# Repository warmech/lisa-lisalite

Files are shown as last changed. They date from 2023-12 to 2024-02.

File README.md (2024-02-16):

# Lisa Lite

The Lisa Lite is an adapter card for the Lisa 2 and 2/5 that allows a Twiggy drive to be replaced by a 400K Sony 3.5" floppy drive. Most of the signals are passed directly from the Twiggy interface to the Sony interface, though the motor clock signal on the Twiggy side is used as the basis (along with a 5MHz oscillator) for generating the PWM signal used to drive the Sony drive.

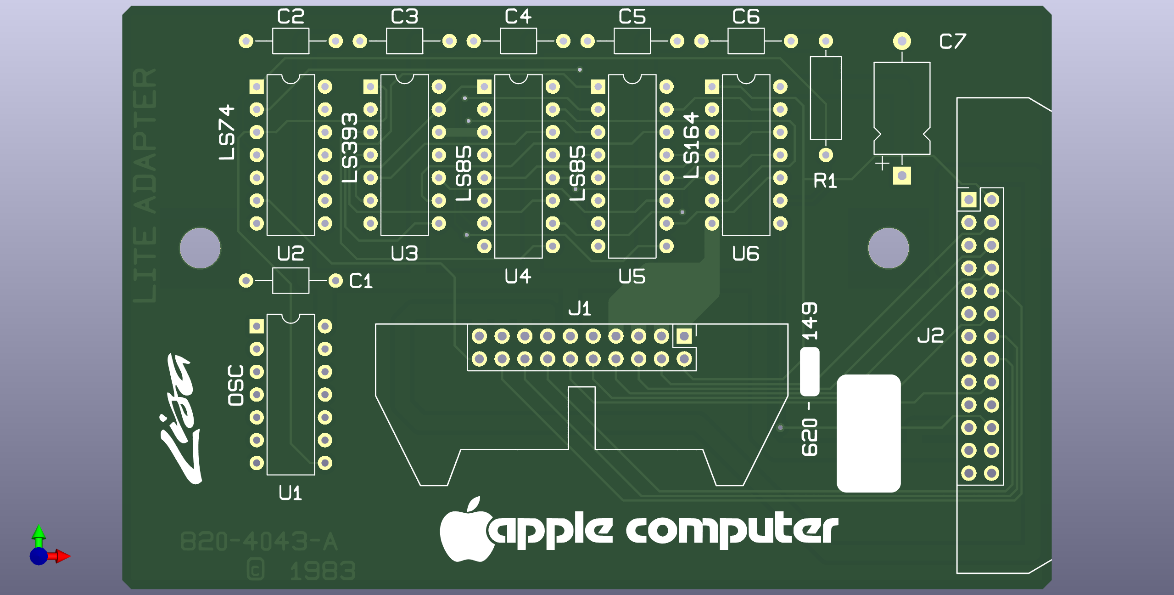
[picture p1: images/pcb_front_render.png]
Lisa Lite Front


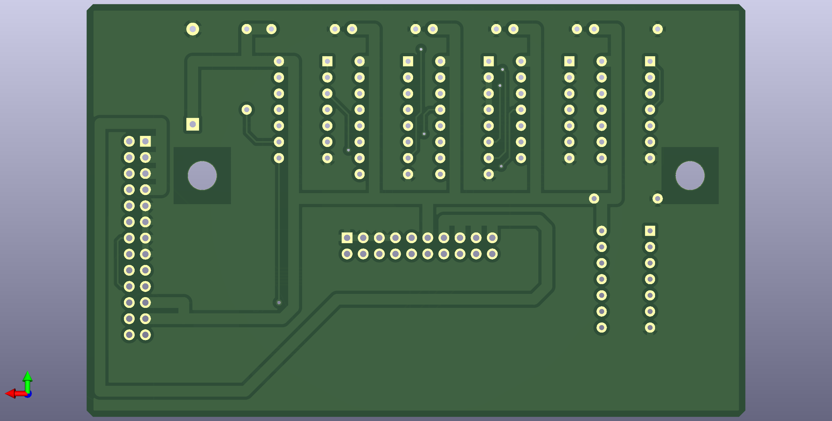
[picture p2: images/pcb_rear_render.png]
Lisa Lite Rear


## Assembly

There is little to explain in terms of assembly, as the card uses relative few components. It should be noted that it is recommended to use keyed connectors for the Twiggy and Sony ribbon cable connectors. Inserting the cables backwards will result in the +12V power rail being piped into the CA0, CA1, CA2, and LSTRB lines on the Sony drive and the READ and MTRCLK lines on the Twiggy interface; this will likely destroy any ICs on these lines and possibly other passive and/or electromechanical components.

## Use

There is also little to explain in terms of installation and use. The Lisa Lite fastens into two standoffs on the side of the internal drive cage closest to the monitor. The wide Twiggy ribbon cable connects to the interface at the rear of the card and the narrow ribbon cable to the interface in the card's middle. A socket may be used for the oscillator if desired, though it's not necessary by any means.

Once the card is installed and connected, no further action is required for use; the card is effectively a passive component itself and the Lisa ROM/IWM manages interfacing with the Sony drive.

## Miscellany

This card is unnecessary on a 2/10, which uses an IC on the I/O card to handle communications with a Sony drive. Additionally, an 800K drive may be used in conjunction with a Sun Remarketing ROM intended for use with the Macintosh XL.

This is a very simple design that I would like to eventually replace with a small CPLD for use in an ATX form-factor Lisa. As it's so tiny a circuit, the Verilog required for this practically writes itself.

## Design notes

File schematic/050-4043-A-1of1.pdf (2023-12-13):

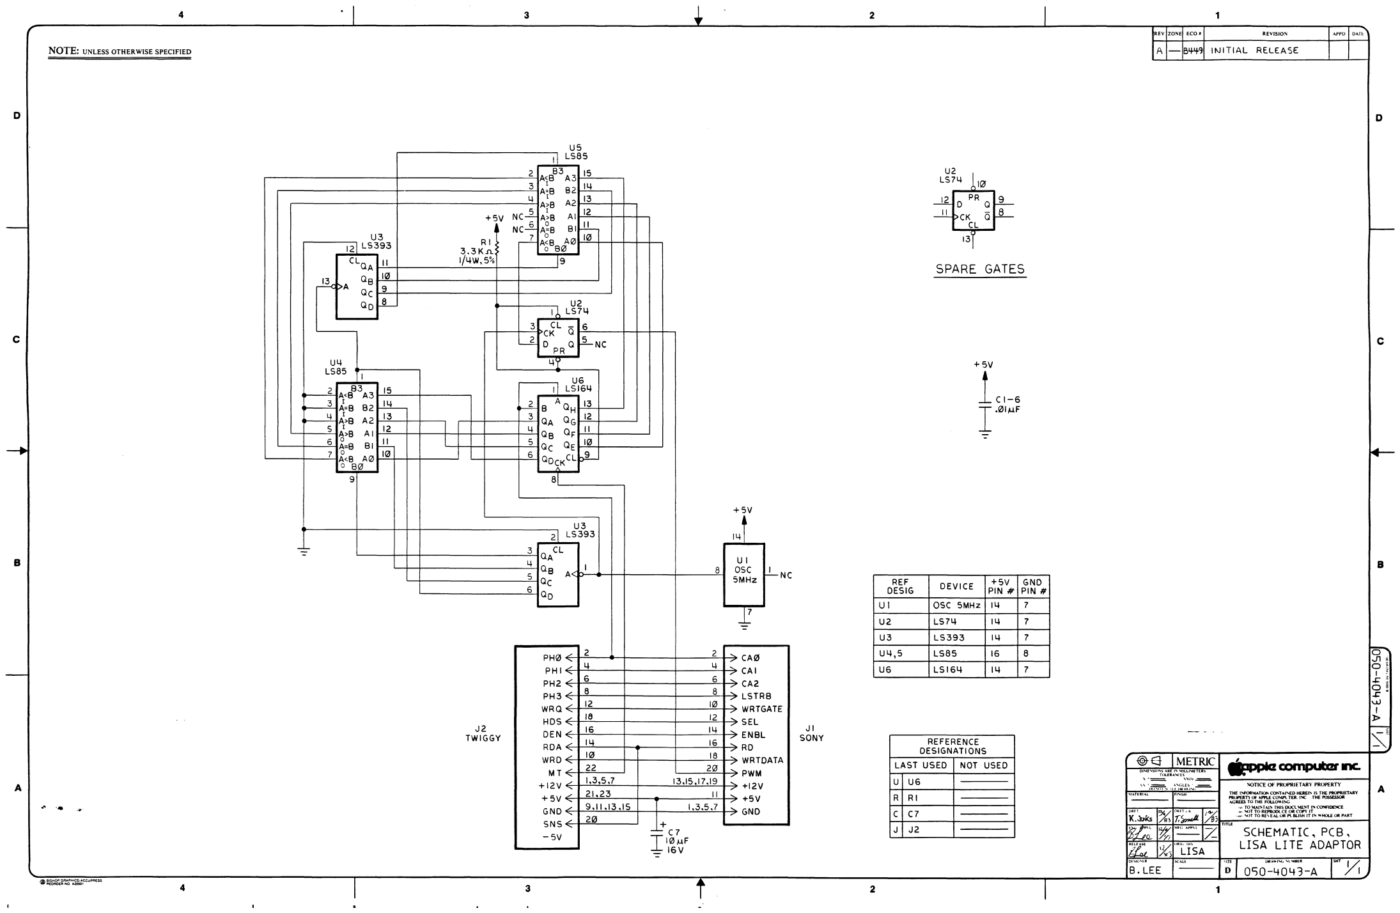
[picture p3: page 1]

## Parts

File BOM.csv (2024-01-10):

# | Reference | Qty | Value | Footprint | DNP
1 | C1, C2, C3, C4, C5, C6 | 6 | 0.1uF 50V | Capacitor_THT:C_Axial_L3.8mm_D2.6mm_P10.00mm_Horizontal
2 | C7 | 1 | 10uF 16V | Capacitor_THT:CP_Axial_L10.0mm_D6.0mm_P15.00mm_Horizontal
3 | J1 | 1 | LisaLite FDD Connector | Connector_PinHeader_2.54mm:PinHeader_2x10_P2.54mm_Vertical
4 | J2 | 1 | LisaLite Twiggy Port Connector | Connector_PinHeader_2.54mm:PinHeader_2x13_P2.54mm_Vertical
5 | R1 | 1 | 3.3K | Resistor_THT:R_Axial_DIN0309_L9.0mm_D3.2mm_P12.70mm_Horizontal
6 | U1 | 1 | 5MHz XTAL | Package_DIP:DIP-14_W7.62mm
7 | U2 | 1 | 74LS74 | Package_DIP:DIP-14_W7.62mm
8 | U3 | 1 | 74LS393 | Package_DIP:DIP-14_W7.62mm
9 | U4, U5 | 2 | 74LS85 | Package_DIP:DIP-16_W7.62mm
10 | U6 | 1 | 74LS164 | Package_DIP:DIP-14_W7.62mm

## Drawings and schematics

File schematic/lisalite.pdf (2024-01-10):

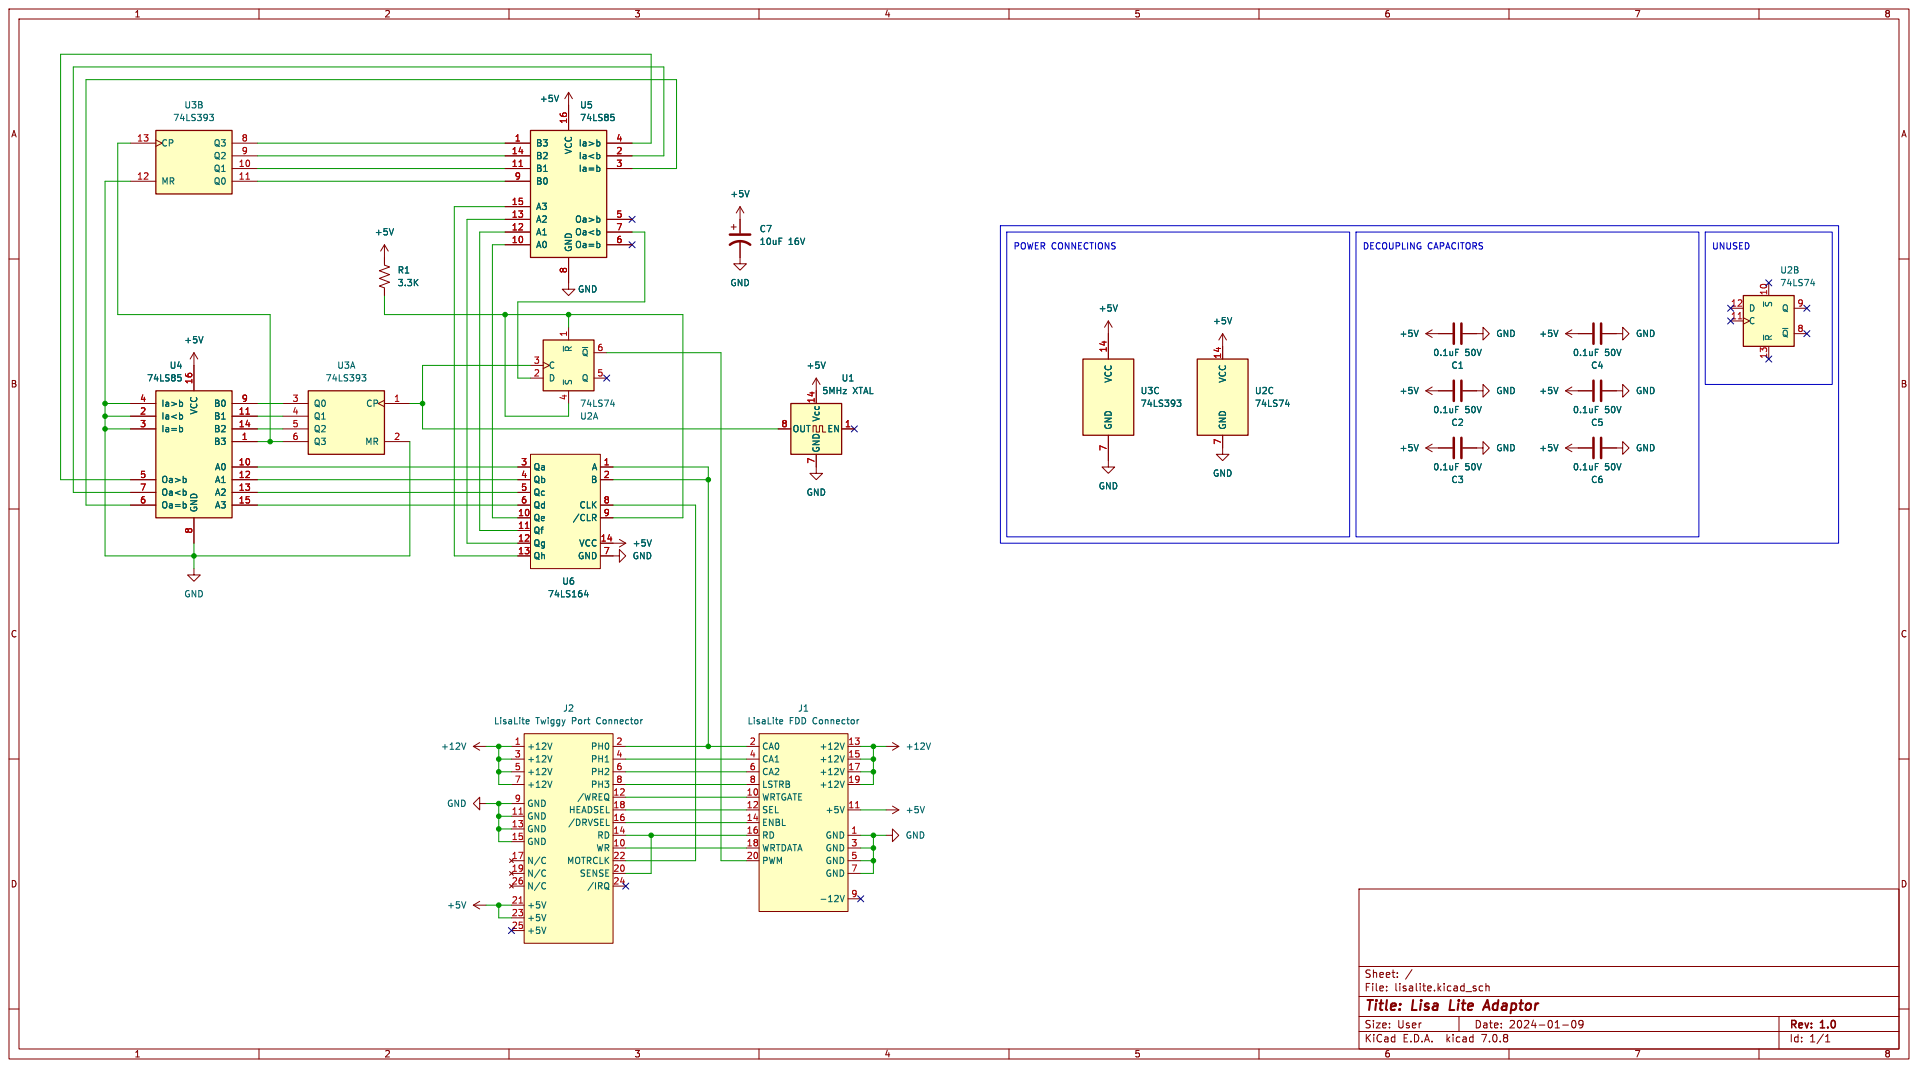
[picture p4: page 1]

LisaLite Twiggy Port Connector +5V

Id: 1/1 Title: Lisa Lite Adaptor File: lisalite.kicad_sch Sheet: /

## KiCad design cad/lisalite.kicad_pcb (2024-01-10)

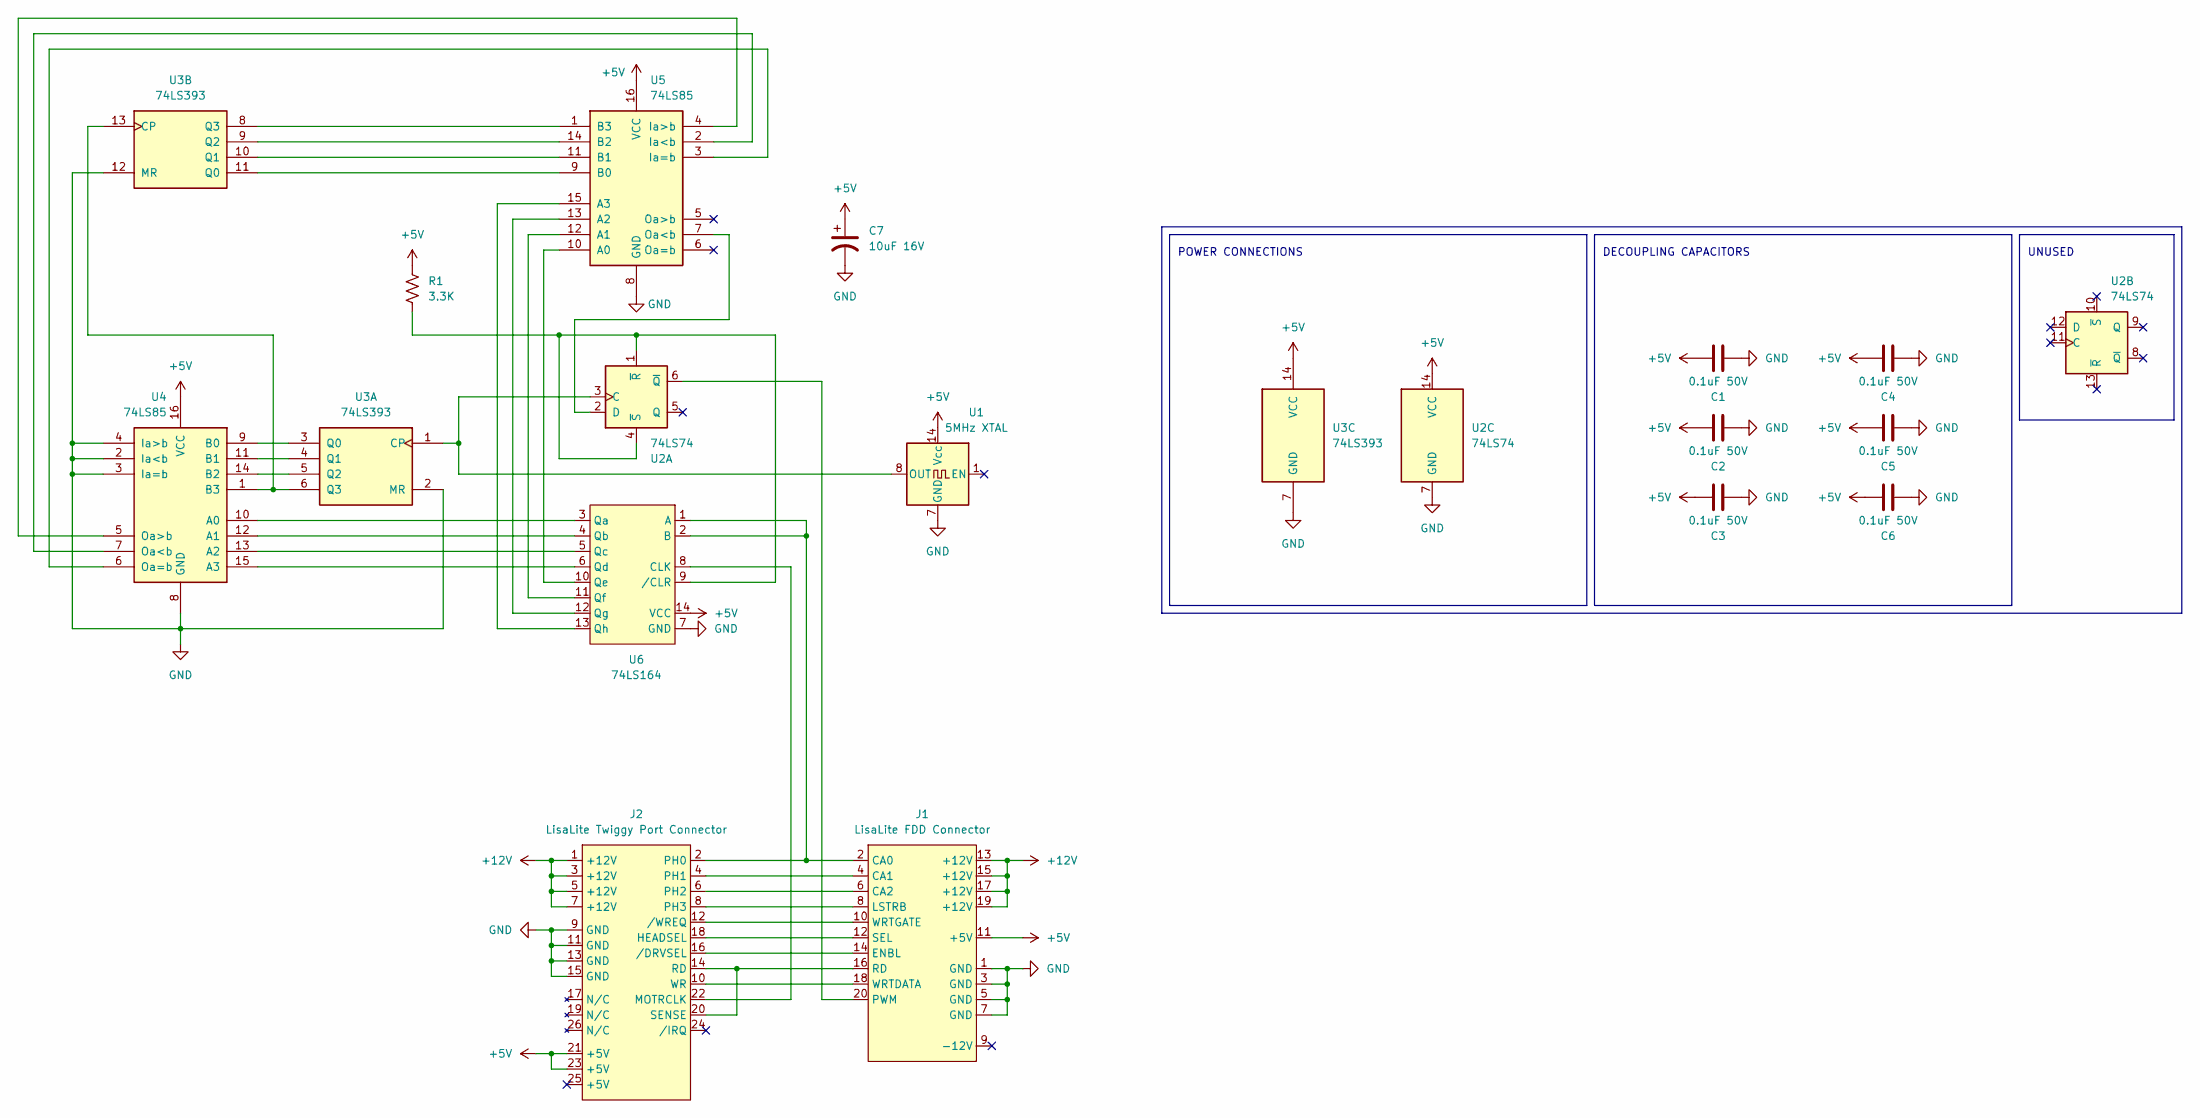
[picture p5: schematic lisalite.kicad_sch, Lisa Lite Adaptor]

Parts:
C1, C2, C3, C4, C5, C6: 0.1uF 50V; C_Axial_L3.8mm_D2.6mm_P10.00mm_Horizontal
C7: 10uF 16V; CP_Axial_L10.0mm_D6.0mm_P15.00mm_Horizontal
J1: LisaLite FDD Connector; PinHeader_2x10_P2.54mm_Vertical
J2: LisaLite Twiggy Port Connector; PinHeader_2x13_P2.54mm_Vertical
R1: 3.3K; R_Axial_DIN0309_L9.0mm_D3.2mm_P12.70mm_Horizontal
U1: 5MHz XTAL; DIP-14_W7.62mm
U2: 74LS74
U3: 74LS393; DIP-14_W7.62mm
U4, U5: 74LS85; DIP-16_W7.62mm
U6: 74LS164; DIP-14_W7.62mm

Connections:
+5V: C1.2, C2.2, C3.2, C4.2, C5.2, C6.2, C7.1, J1.11 (+5V), J2.21 (+5V), J2.23 (+5V), R1.1, U1.14 (Vcc), U2.14 (VCC), U3.14 (VCC), U4.16 (VCC), U5.16 (VCC), U6.14 (VCC)
+12V: J1.13 (+12V), J1.15 (+12V), J1.17 (+12V), J1.19 (+12V), J2.1 (+12V), J2.3 (+12V), J2.5 (+12V), J2.7 (+12V)
GND: C1.1, C2.1, C3.1, C4.1, C5.1, C6.1, C7.2, J1.1 (GND), J1.3 (GND), J1.5 (GND), J1.7 (GND), J2.9 (GND), J2.11 (GND), J2.13 (GND), J2.15 (GND), U1.7 (GND), U2.7 (GND), U3.2 (MR), U3.7 (GND), U3.12 (MR), U4.2 (Ia<b), U4.3 (Ia=b), U4.4 (Ia>b), U4.8 (GND), U5.8 (GND), U6.7 (GND)
unnamed: J1.2 (CA0), J2.2 (PH0), U6.1 (A), U6.2 (B)
unnamed: J1.4 (CA1), J2.4 (PH1)
unnamed: J1.6 (CA2), J2.6 (PH2)
unnamed: J1.14 (ENBL), J2.16 (/DRVSEL)
unnamed: J1.8 (LSTRB), J2.8 (PH3)
unnamed: J1.20 (PWM), U2.6 (~Q)
unnamed: J1.16 (RD), J2.14 (RD), J2.20 (SENSE)
unnamed: J1.12 (SEL), J2.18 (HEADSEL)
unnamed: J1.18 (WRTDATA), J2.10 (WR)
unnamed: J1.10 (WRTGATE), J2.12 (/WREQ)
unnamed: J2.22 (MOTRCLK), U6.8 (CLK)
unnamed: U1.8 (OUT), U2.3 (C), U3.1 (CP)
unnamed: U2.2 (D), U5.7 (Oa<b)
unnamed: R1.2, U2.1 (~R), U2.4 (~S), U6.9 (/CLR)
unnamed: U3.3 (Q0), U4.9 (B0)
unnamed: U3.4 (Q1), U4.11 (B1)
unnamed: U3.5 (Q2), U4.14 (B2)
unnamed: U3.6 (Q3), U3.13 (CP), U4.1 (B3)
unnamed: U3.11 (Q0), U5.9 (B0)
unnamed: U3.10 (Q1), U5.11 (B1)
unnamed: U3.9 (Q2), U5.14 (B2)
unnamed: U3.8 (Q3), U5.1 (B3)
unnamed: U4.10 (A0), U6.3 (Qa)
unnamed: U4.12 (A1), U6.4 (Qb)
unnamed: U4.13 (A2), U6.5 (Qc)
unnamed: U4.15 (A3), U6.6 (Qd)
unnamed: U4.7 (Oa<b), U5.2 (Ia<b)
unnamed: U4.6 (Oa=b), U5.3 (Ia=b)
unnamed: U4.5 (Oa>b), U5.4 (Ia>b)
unnamed: U5.10 (A0), U6.10 (Qe)
unnamed: U5.12 (A1), U6.11 (Qf)
unnamed: U5.13 (A2), U6.12 (Qg)
unnamed: U5.15 (A3), U6.13 (Qh)

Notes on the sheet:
UNUSED
DECOUPLING CAPACITORS
POWER CONNECTIONS

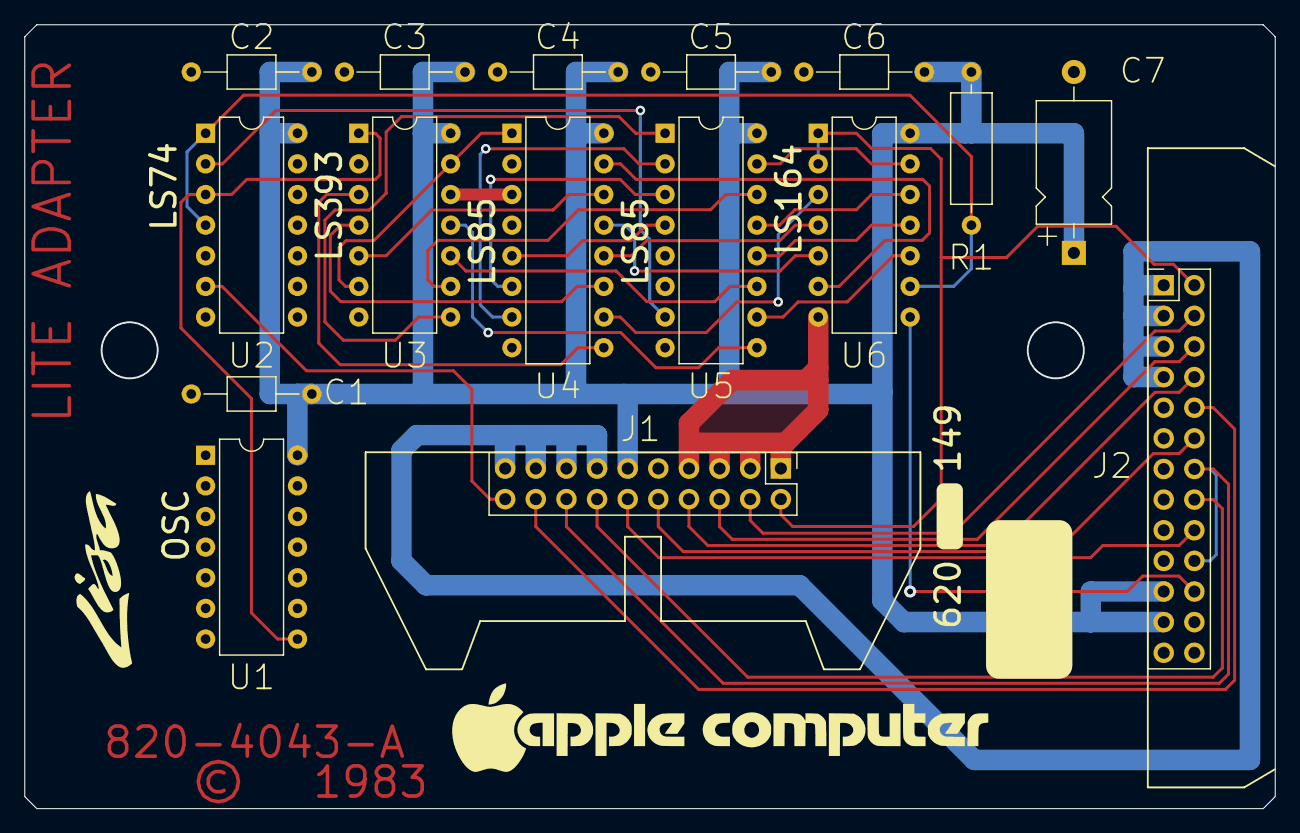
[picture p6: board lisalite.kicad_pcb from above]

Board: 2 copper layers, 103.7 x 65.0 mm, 16 parts (0 on the bottom side), 36 nets.

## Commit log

2023-12-12 init schematic
    [lisalite.kicad_pcb, lisalite.kicad_sch]
2023-12-13 schematic updates
    [lisalite.kicad_sch]
2024-01-08 generated pcb
    [lisalite.kicad_pcb, lisalite.kicad_sch]
2024-01-10 final commit for rev 1.0
    [lisalite.kicad_pcb, lisalite.kicad_sch]
2024-01-10 readme and cad dir rename
    [BOM.csv, lisalite.kicad_pcb, lisalite.kicad_sch]
2024-01-10 final silkscreen adds; re-rendered images
    [lisalite.kicad_pcb]

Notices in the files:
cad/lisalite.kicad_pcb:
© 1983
